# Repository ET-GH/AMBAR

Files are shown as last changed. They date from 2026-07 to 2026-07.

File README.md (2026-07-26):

# AMBAR
The software and hardware of the AMBAR project

Utilized Firmware includes all the logic used for our system.

Measurement & Control includes logic and API used for the measurement and control of the system. Airbrake.c includes references to a tmc5240 driver. Utilized Firmware has the completed driver but if your system used something else then changes must be made in the airbrake logic.

Communication includes logic and api used for communication and data between the flight computer and ground station. radio_bridge includes references to an sx1280 driver. Utilized Firmware has the completed driver but if your system used something else then changes must be made in the bridge logic. usb_comm includes references to the STM32 USB drivers. Utilized Firmware has the completed driver but if your system used something else then changes must be made in the usb logic.

GroundStation includes all the files used for qt application. Qt libraries were used for each of the integration files. The architecture can still be used if you don't want to use QT but the function calls will not work without the installed QT libraries.

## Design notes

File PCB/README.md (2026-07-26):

# AMBAR Flight Computer PCB
What we used for our project. You can buy all the components off of JLCPCB and Digikey

Export the gerber files and the bill of materials. Purchase the electrical componetns from digikey if you plan to solder but it's much easier to simply ask JLCPCB to fabricate and assemble the board.

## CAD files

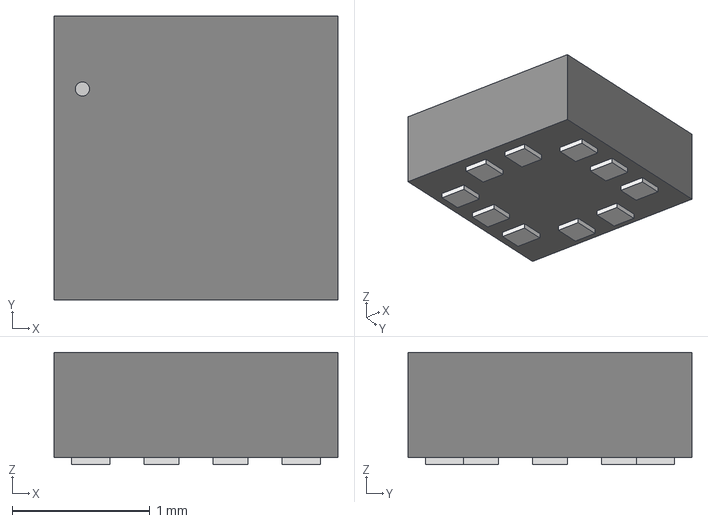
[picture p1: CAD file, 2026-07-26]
PCB/components/ul_BMP388/QFN_BMP388_BOS.step
2.06 x 2.06 x 0.815 mm

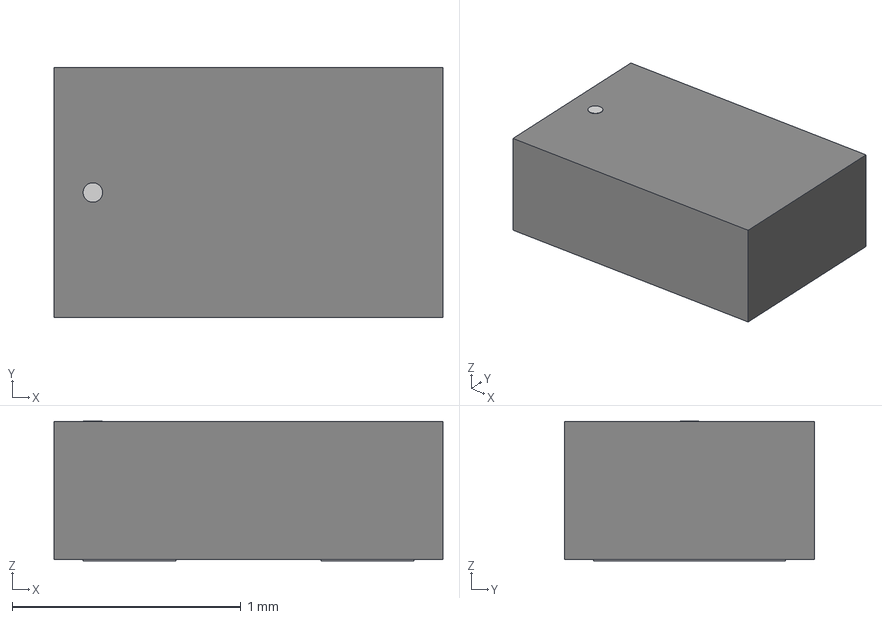
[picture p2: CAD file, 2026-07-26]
PCB/components/ul_ESDA7P60-1U1M/ZDO_1610_STM.step
1.70 x 1.09 x 0.612 mm

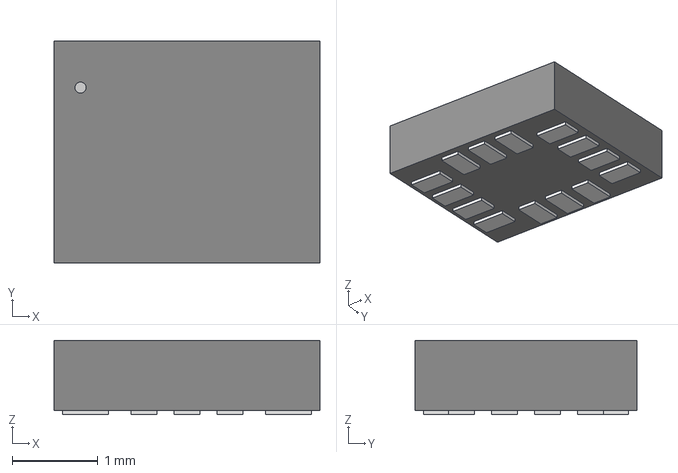
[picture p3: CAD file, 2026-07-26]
PCB/components/ul_LSM6DSV32XTR/LGA-14L_2p5X3p0X0p86_STM.step
3.10 x 2.59 x 0.866 mm

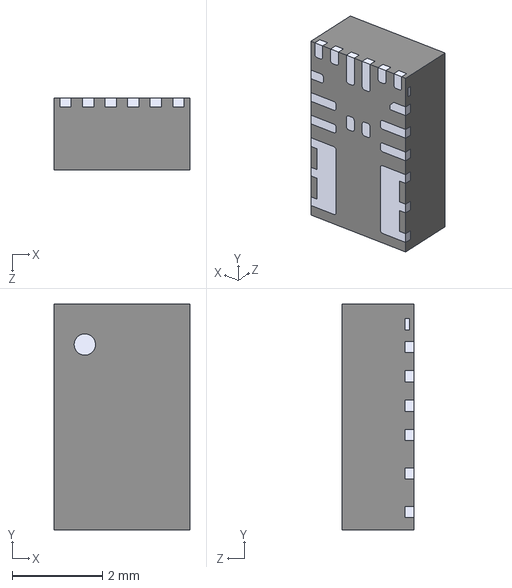
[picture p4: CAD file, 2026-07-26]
PCB/components/ul_MPM3606AGQV-Z/MPM3606AGQV.step
3.00 x 5.00 x 1.60 mm

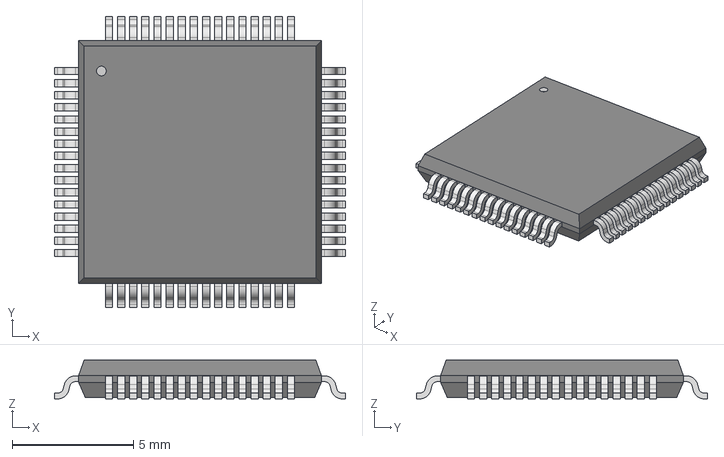
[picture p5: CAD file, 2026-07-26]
PCB/components/ul_STM32H562RGT6/LQFP64-10x10mm_STM.step
12.0 x 12.0 x 1.60 mm

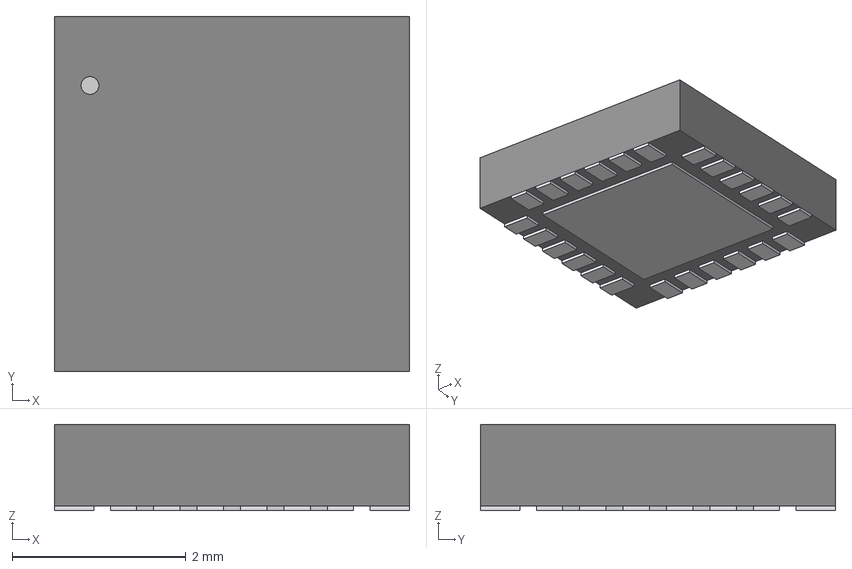
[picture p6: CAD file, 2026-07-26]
PCB/components/ul_SX1280IMLTRT/QFN24_4X4_SEM.step
4.09 x 4.09 x 0.993 mm

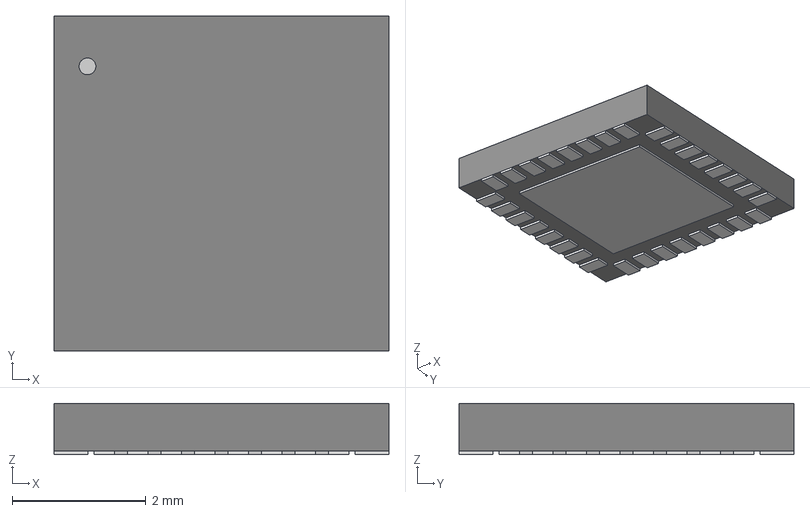
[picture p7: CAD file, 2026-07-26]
PCB/components/ul_TMC5240ATJ-T/21-0140_T32555C_ADI.step
5.00 x 5.00 x 0.765 mm

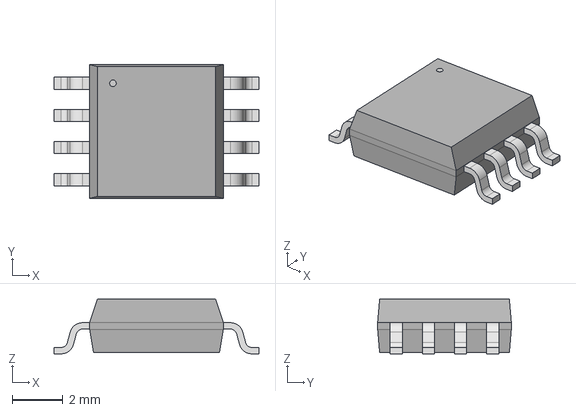
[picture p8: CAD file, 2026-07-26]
PCB/components/ul_W25Q64JVSSIQ/SOIC-8_5P28X5P28_WIN.step
8.10 x 5.28 x 2.16 mm

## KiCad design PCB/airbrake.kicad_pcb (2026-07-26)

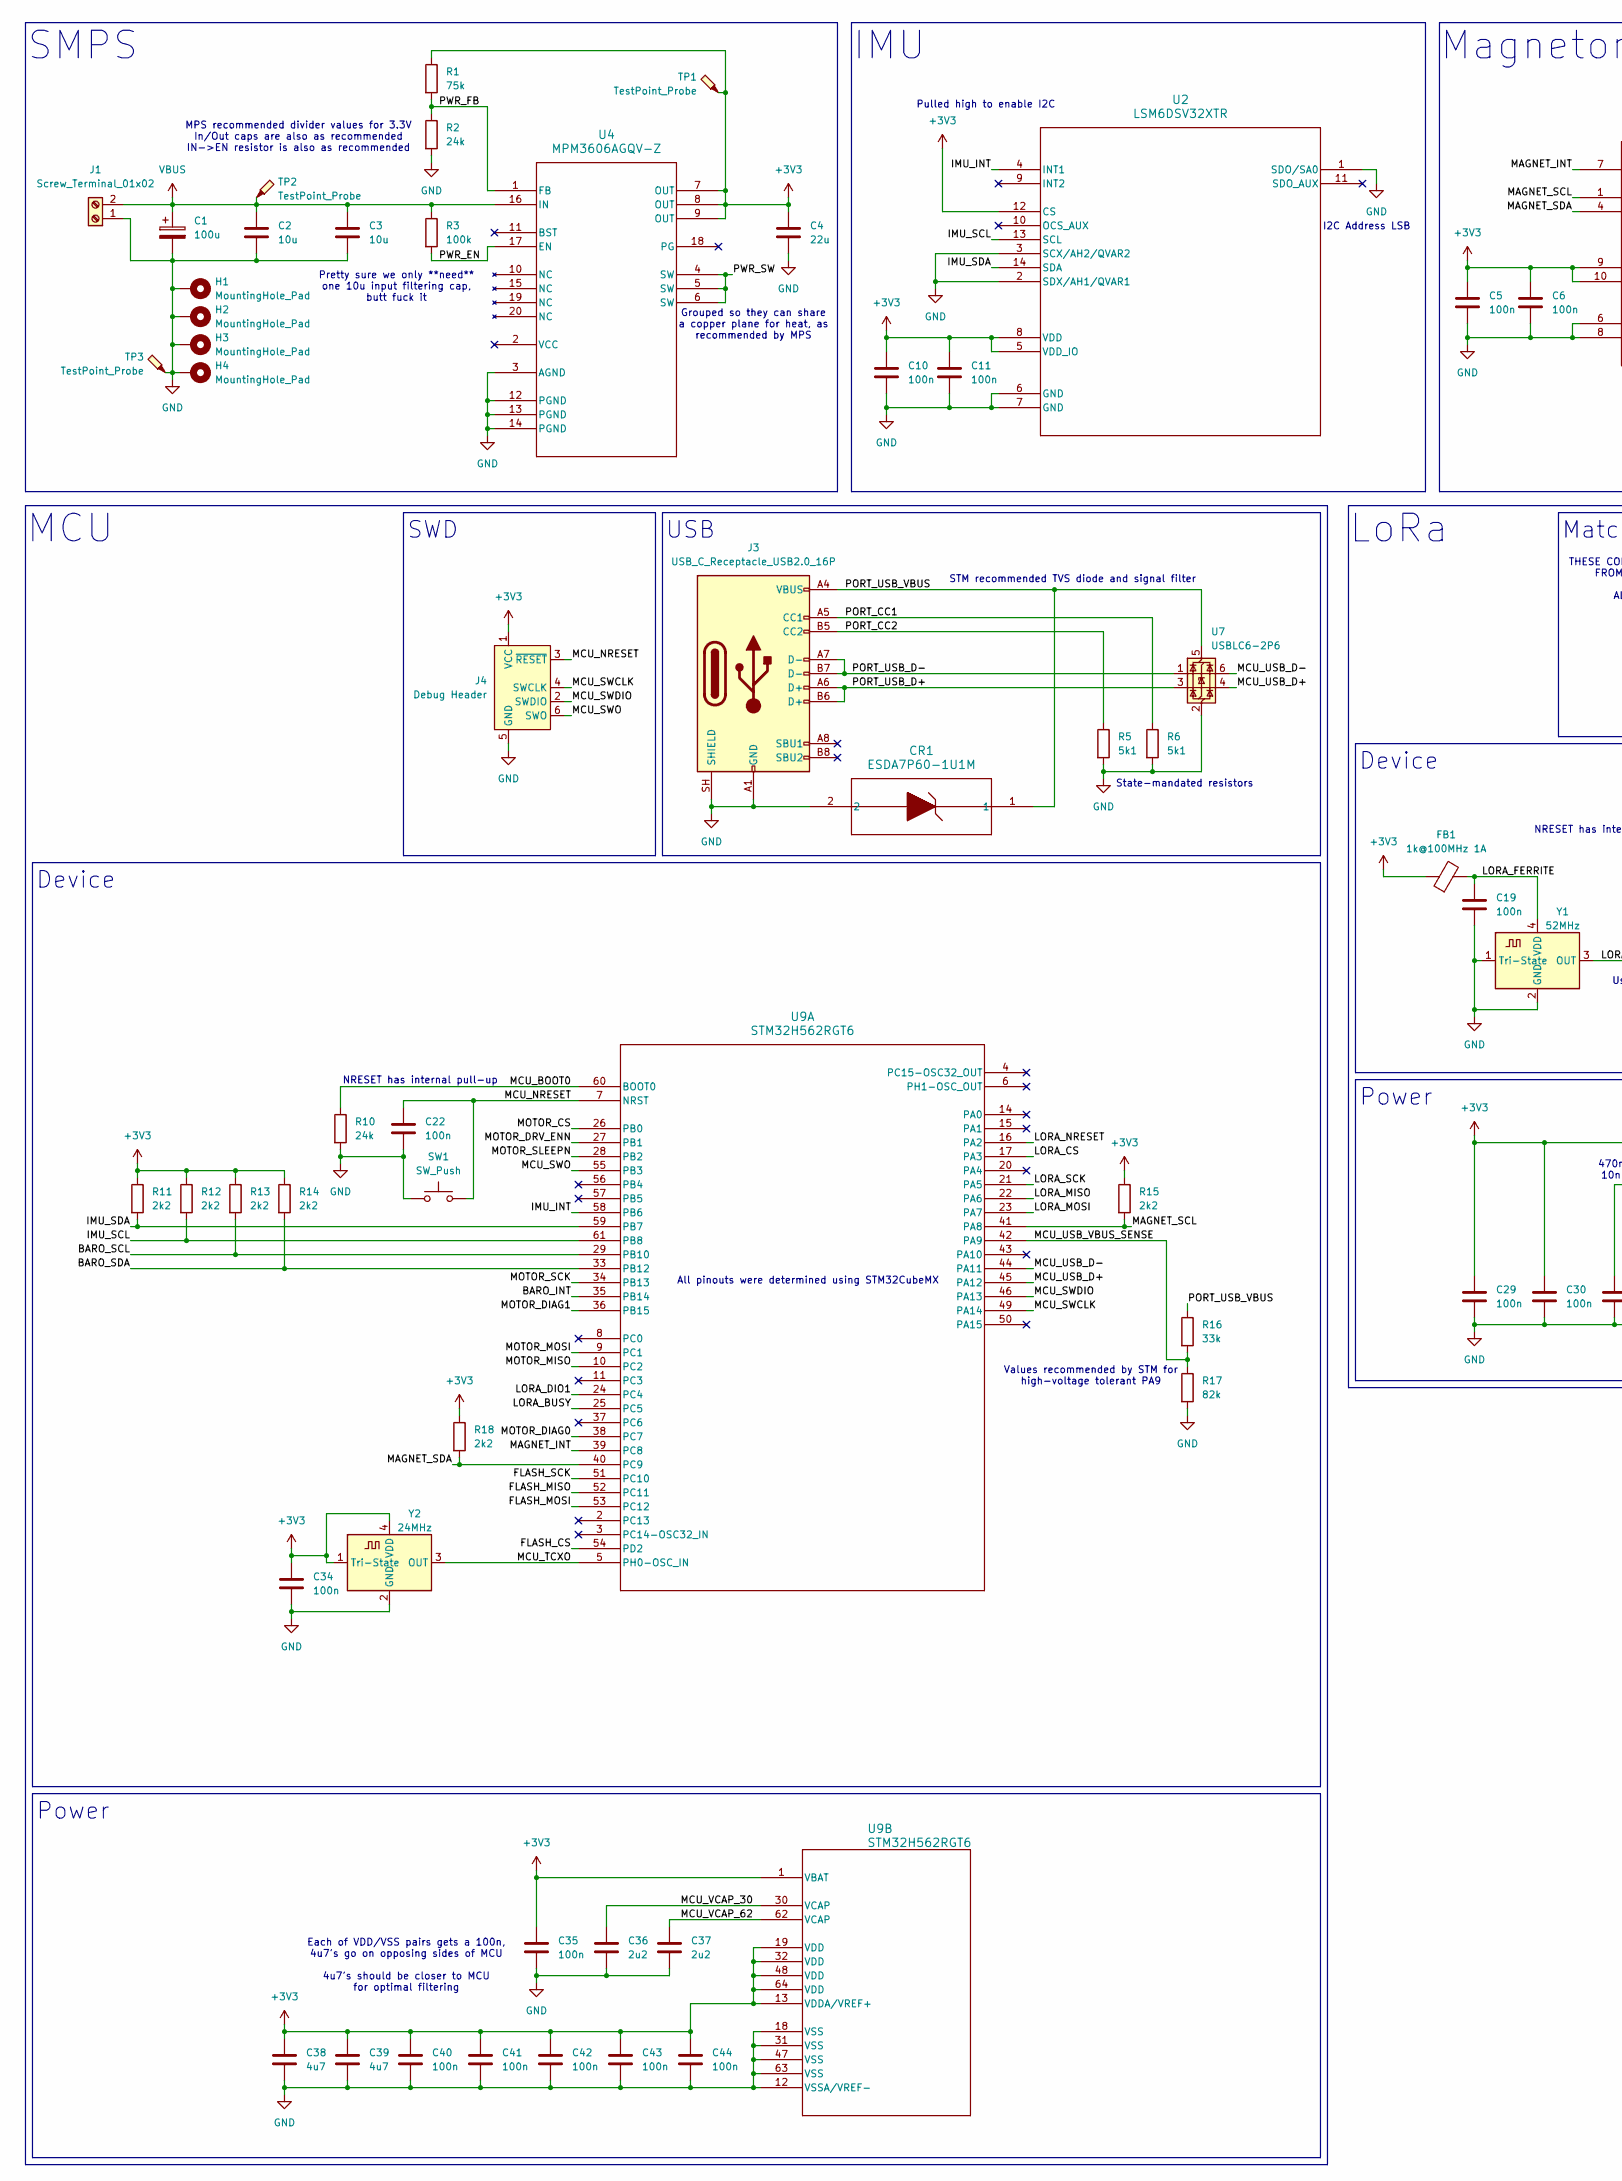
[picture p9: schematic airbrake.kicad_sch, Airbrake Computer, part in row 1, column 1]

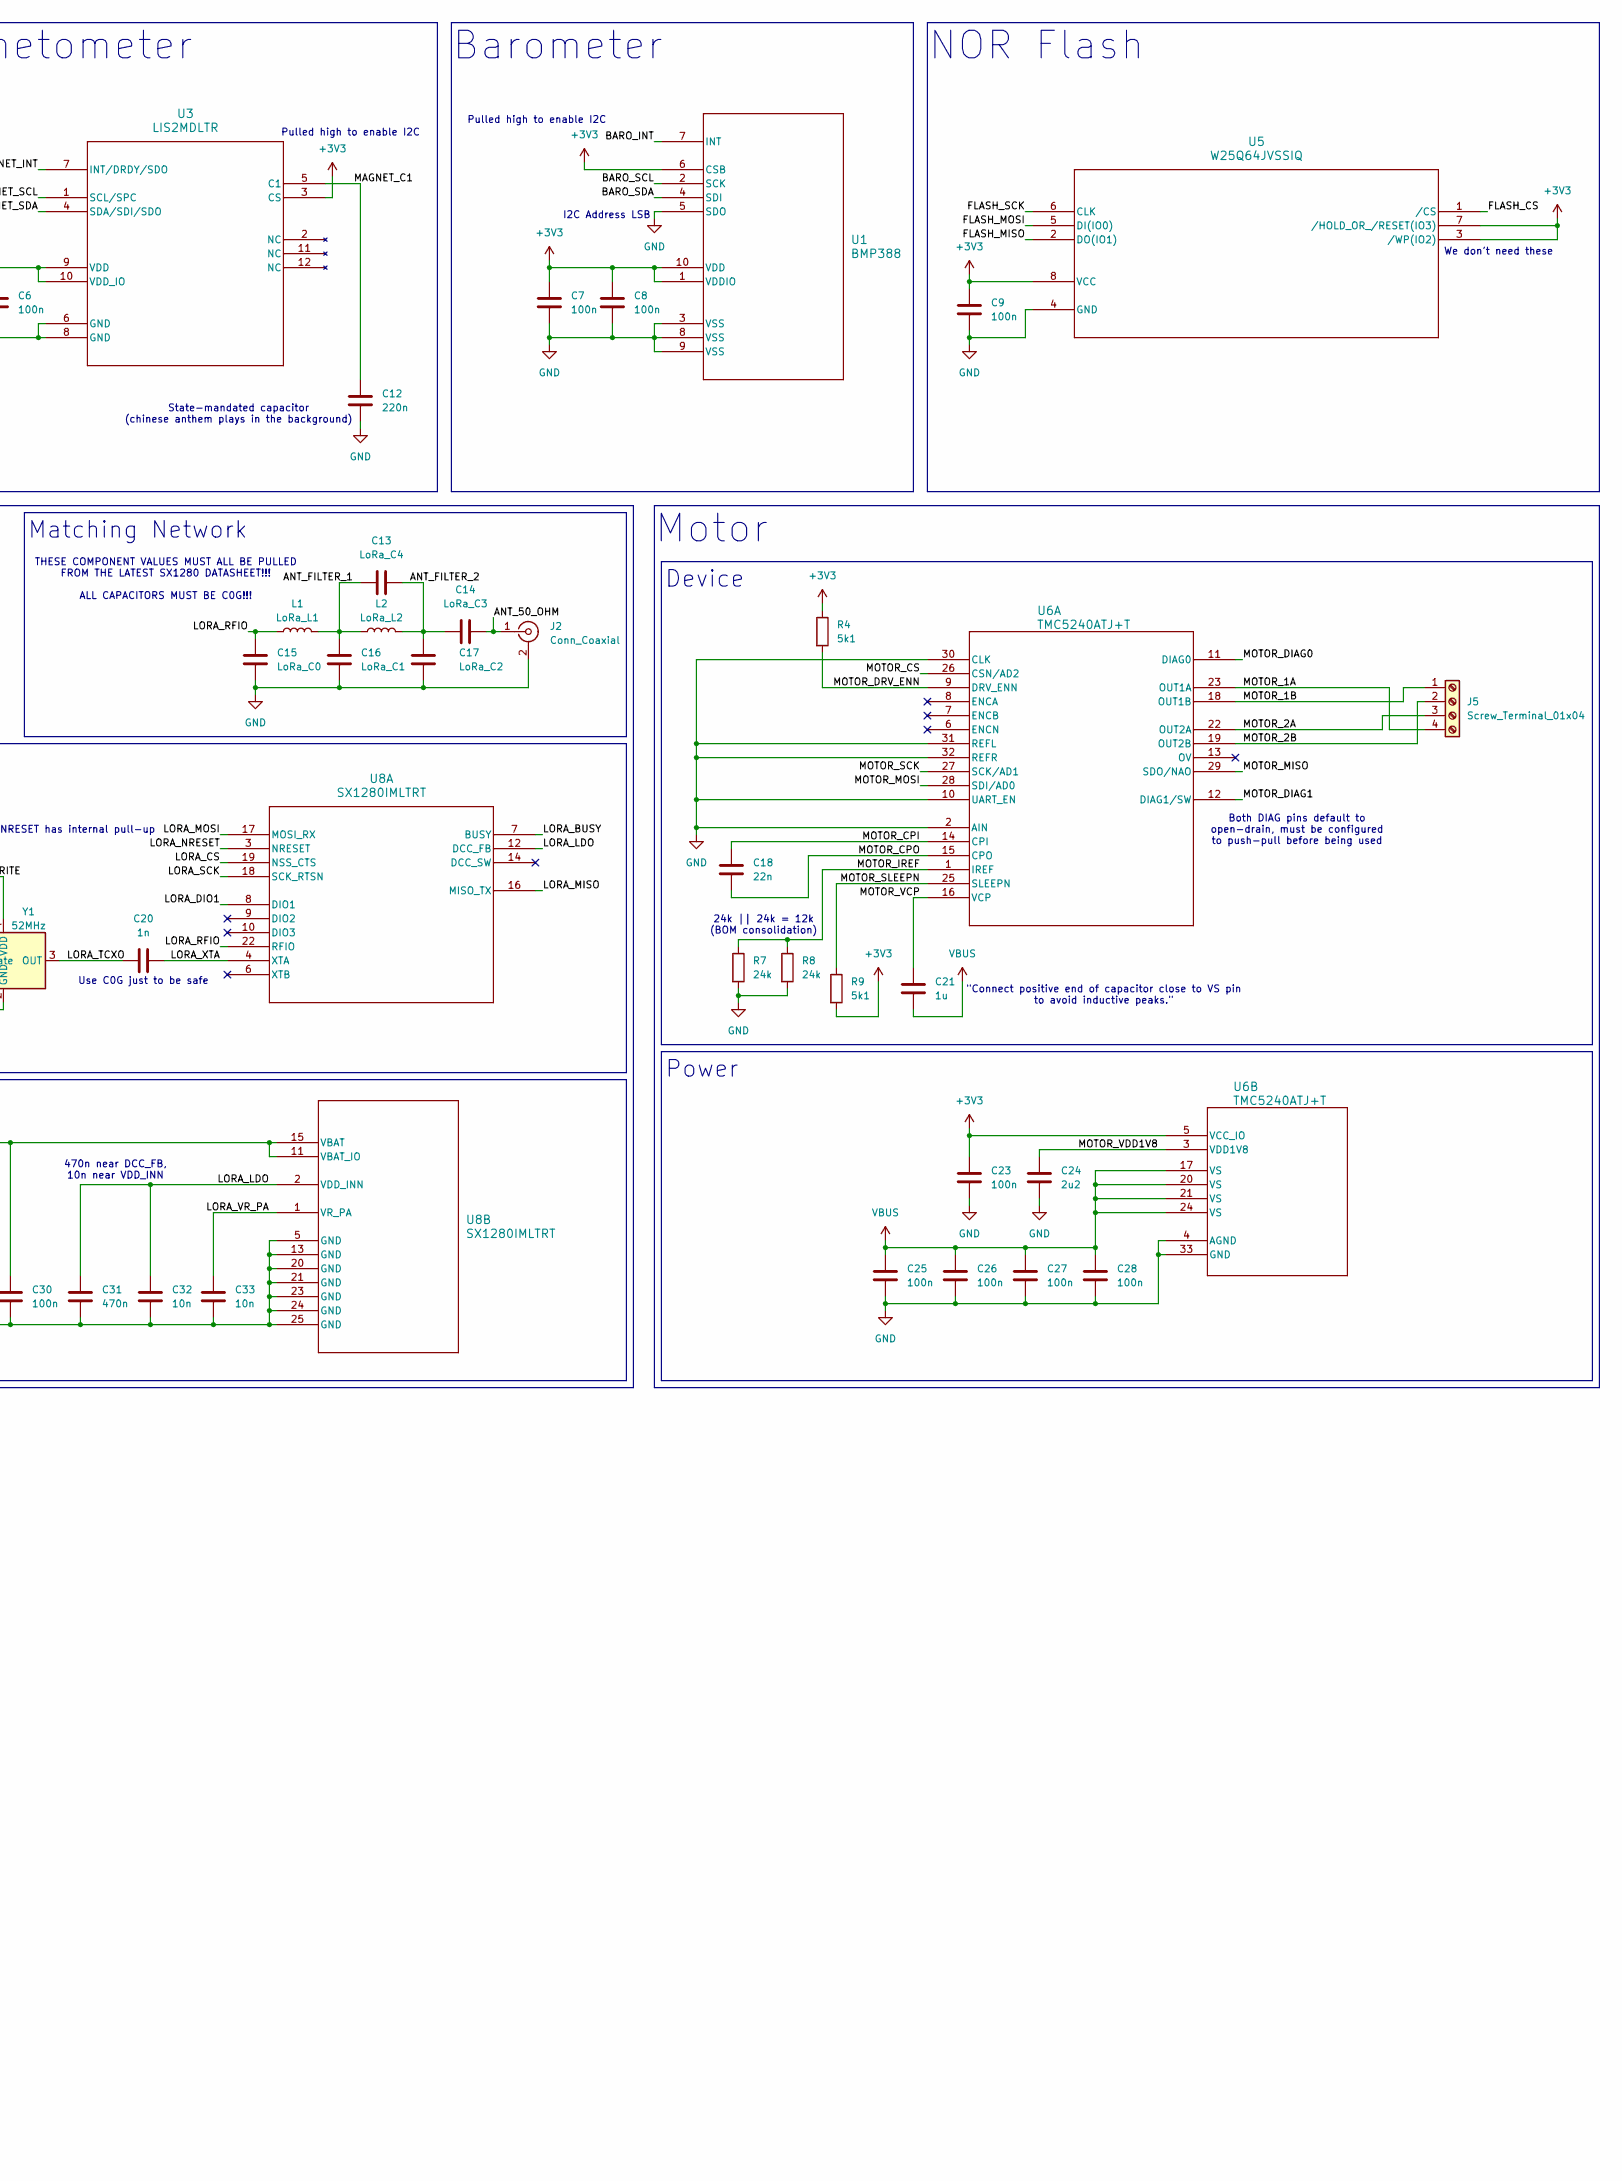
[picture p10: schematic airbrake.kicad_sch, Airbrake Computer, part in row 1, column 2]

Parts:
C1: 100u; CP_Elec_6.3x7.7
C2, C3: 10u; C_0603_1608Metric
C4: 22u; C_0603_1608Metric
C5, C6, C7, C8, C9, C10, C11, C19, C22, C23, C25, C26, C27, C28, C29, C30, C34, C35, C40, C41, C42, C43, C44: 100n; C_0402_1005Metric
C12: 220n; C_0402_1005Metric
C13: LoRa_C4; C_0402_1005Metric
C14: LoRa_C3; C_0402_1005Metric
C15: LoRa_C0; C_0402_1005Metric
C16: LoRa_C1; C_0402_1005Metric
C17: LoRa_C2; C_0402_1005Metric
C18: 22n; C_0402_1005Metric
C20: 1n; C_0402_1005Metric
C21: 1u; C_0402_1005Metric
C24, C36, C37: 2u2; C_0402_1005Metric
C31: 470n; C_0402_1005Metric
C32, C33: 10n; C_0402_1005Metric
C38, C39: 4u7; C_0402_1005Metric
CR1: ESDA7P60-1U1M; ZDO_1610_STM
FB1: 1k@100MHz 1A; L_0603_1608Metric
H1, H2, H3, H4: MountingHole_Pad; MountingHole_2.2mm_M2_Pad_Via
J1: Screw_Terminal_01x02; TerminalBlock_Xinya_XY308-2.54-2P_1x02_P2.54mm_Horizontal
J2: Conn_Coaxial; U.FL_Hirose_U.FL-R-SMT-1_Vertical
J3: USB_C_Receptacle_USB2.0_16P; USB_C_Receptacle_GCT_USB4105-xx-A_16P_TopMnt_Horizontal
J4: Debug Header; Tag-Connect_TC2030-IDC-NL_2x03_P1.27mm_Vertical
J5: Screw_Terminal_01x04; TerminalBlock_Xinya_XY308-2.54-4P_1x04_P2.54mm_Horizontal
L1: LoRa_L1; L_0402_1005Metric
L2: LoRa_L2; L_0402_1005Metric
R1: 75k; R_0402_1005Metric
R2, R7, R8, R10: 24k; R_0402_1005Metric
R3: 100k; R_0402_1005Metric
R4, R5, R6, R9: 5k1; R_0402_1005Metric
R11, R12, R13, R14, R15, R18: 2k2; R_0402_1005Metric
R16: 33k; R_0402_1005Metric
R17: 82k; R_0402_1005Metric
SW1: SW_Push; SW_SPST_B3U-1000P
TP1, TP2, TP3: TestPoint_Probe; TestPoint_Pad_D2.5mm
U1: BMP388; QFN_BMP388_BOS
U2: LSM6DSV32XTR; LGA-14L_2p5X3p0X0p86_STM
U3: LIS2MDLTR; LGA-12_2X2X1_STM
U4: MPM3606AGQV-Z; QFN3p0x5p0x1p6_MPM3606A_MNP
U5: W25Q64JVSSIQ; SOIC-8_5P28X5P28_WIN-L
U6: TMC5240ATJ+T; 21-0140_T3255&plus_5C_ADI-L
U7: USBLC6-2P6; SOT-666
U8: SX1280IMLTRT; QFN24_4X4_SEM-L
U9: STM32H562RGT6; LQFP64-10x10mm_STM
Y1: 52MHz; Crystal_SMD_2016-4Pin_2.0x1.6mm
Y2: 24MHz; Crystal_SMD_2520-4Pin_2.5x2.0mm

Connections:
+3V3: C4.1, C5.1, C6.1, C7.1, C8.1, C9.1, C10.1, C11.1, C23.1, C29.1, C30.1, C34.1, C35.1, C38.1, C39.1, C40.1, C41.1, C42.1, C43.1, C44.1, FB1.1, J4.1 (VCC), R1.1, R4.1, R9.2, R11.1, R12.1, R13.1, R14.1, R15.1, R18.1, TP1.1 (1_1), U1.1 (VDDIO), U1.6 (CSB), U1.10 (VDD), U2.5 (VDD_IO), U2.8 (VDD), U2.12 (CS), U3.3 (CS), U3.9 (VDD), U3.10 (VDD_IO), U4.7 (OUT), U4.8 (OUT), U4.9 (OUT), U5.3 (/WP(IO2)), U5.7 (/HOLD_OR_/RESET(IO3)), U5.8 (VCC), U6.5 (VCC_IO), U8.11 (VBAT_IO), U8.15 (VBAT), U9.1 (VBAT), U9.13 (VDDA/VREF+), U9.19 (VDD), U9.32 (VDD), U9.48 (VDD), U9.64 (VDD), Y2.1 (Tri-State), Y2.4 (VDD)
/ANT_50_OHM: C14.2, J2.1 (In)
/ANT_FILTER_1: C13.1, C16.1, L1.2, L2.1
/ANT_FILTER_2: C13.2, C14.1, C17.1, L2.2
/BARO_INT: U1.7 (INT), U9.35 (PB14)
/BARO_SCL: R13.2, U1.2 (SCK), U9.29 (PB10)
/BARO_SDA: R14.2, U1.4 (SDI), U9.33 (PB12)
/FLASH_CS: U5.1 (/CS), U9.54 (PD2)
/FLASH_MISO: U5.2 (DO(IO1)), U9.52 (PC11)
/FLASH_MOSI: U5.5 (DI(IO0)), U9.53 (PC12)
/FLASH_SCK: U5.6 (CLK), U9.51 (PC10)
/IMU_INT: U2.4 (INT1), U9.58 (PB6)
/IMU_SCL: R12.2, U2.13 (SCL), U9.61 (PB8)
/IMU_SDA: R11.2, U2.14 (SDA), U9.59 (PB7)
/LORA_BUSY: U8.7 (BUSY), U9.25 (PC5)
/LORA_CS: U8.19 (NSS_CTS), U9.17 (PA3)
/LORA_DIO1: U8.8 (DIO1), U9.24 (PC4)
/LORA_FERRITE: C19.1, FB1.2, Y1.4 (VDD)
/LORA_LDO: C31.1, C32.1, U8.2 (VDD_INN), U8.12 (DCC_FB)
/LORA_MISO: U8.16 (MISO_TX), U9.22 (PA6)
/LORA_MOSI: U8.17 (MOSI_RX), U9.23 (PA7)
/LORA_NRESET: U8.3 (NRESET), U9.16 (PA2)
/LORA_RFIO: C15.1, L1.1, U8.22 (RFIO)
/LORA_SCK: U8.18 (SCK_RTSN), U9.21 (PA5)
/LORA_TCXO: C20.1, Y1.3 (OUT)
/LORA_VR_PA: C33.1, U8.1 (VR_PA)
/LORA_XTA: C20.2, U8.4 (XTA)
/MAGNET_C1: C12.1, U3.5 (C1)
/MAGNET_INT: U3.7 (INT/DRDY/SDO), U9.39 (PC8)
/MAGNET_SCL: R15.2, U3.1 (SCL/SPC), U9.41 (PA8)
/MAGNET_SDA: R18.2, U3.4 (SDA/SDI/SDO), U9.40 (PC9)
/MCU_BOOT0: R10.1, U9.60 (BOOT0)
/MCU_NRESET: C22.1, J4.3 (~RESET), SW1.2, U9.7 (NRST)
/MCU_SWCLK: J4.4 (SWCLK), U9.49 (PA14)
/MCU_SWDIO: J4.2 (SWDIO), U9.46 (PA13)
/MCU_SWO: J4.6 (SWO), U9.55 (PB3)
/MCU_TCXO: U9.5 (PH0-OSC_IN), Y2.3 (OUT)
/MCU_USB_D+: U7.4 (I/O2), U9.45 (PA12)
/MCU_USB_D-: U7.6 (I/O1), U9.44 (PA11)
/MCU_USB_VBUS_SENSE: R16.2, R17.1, U9.42 (PA9)
/MCU_VCAP_30: C36.1, U9.30 (VCAP)
/MCU_VCAP_62: C37.1, U9.62 (VCAP)
/MOTOR_1A: J5.4, U6.23 (OUT1A)
/MOTOR_1B: J5.1, U6.18 (OUT1B)
/MOTOR_2A: J5.3, U6.22 (OUT2A)
/MOTOR_2B: J5.2, U6.19 (OUT2B)
/MOTOR_CPI: C18.1, U6.14 (CPI)
/MOTOR_CPO: C18.2, U6.15 (CPO)
/MOTOR_CS: U6.26 (CSN/AD2), U9.26 (PB0)
/MOTOR_DIAG0: U6.11 (DIAG0), U9.38 (PC7)
/MOTOR_DIAG1: U6.12 (DIAG1/SW), U9.36 (PB15)
/MOTOR_DRV_ENN: R4.2, U6.9 (DRV_ENN), U9.27 (PB1)
/MOTOR_IREF: R7.1, R8.1, U6.1 (IREF)
/MOTOR_MISO: U6.29 (SDO/NAO), U9.10 (PC2)
/MOTOR_MOSI: U6.28 (SDI/AD0), U9.9 (PC1)
/MOTOR_SCK: U6.27 (SCK/AD1), U9.34 (PB13)
/MOTOR_SLEEPN: R9.1, U6.25 (SLEEPN), U9.28 (PB2)
/MOTOR_VCP: C21.1, U6.16 (VCP)
/MOTOR_VDD1V8: C24.1, U6.3 (VDD1V8)
/PORT_CC1: J3.A5 (CC1), R6.1
/PORT_CC2: J3.B5 (CC2), R5.1
/PORT_USB_D+: J3.A6 (D+), J3.B6 (D+), U7.3 (I/O2)
/PORT_USB_D-: J3.A7 (D-), J3.B7 (D-), U7.1 (I/O1)
/PORT_USB_VBUS: CR1.1, J3.A4 (VBUS), J3.A9 (VBUS), J3.B4 (VBUS), J3.B9 (VBUS), R16.1, U7.5 (VBUS)
/PWR_EN: R3.2, U4.17 (EN)
/PWR_FB: R1.2, R2.1, U4.1 (FB)
/PWR_SW: U4.4 (SW), U4.5 (SW), U4.6 (SW)
GND: C1.2, C2.2, C3.2, C4.2, C5.2, C6.2, C7.2, C8.2, C9.2, C10.2, C11.2, C12.2, C15.2, C16.2, C17.2, C19.2, C22.2, C23.2, C24.2, C25.2, C26.2, C27.2, C28.2, C29.2, C30.2, C31.2, C32.2, C33.2, C34.2, C35.2, C36.2, C37.2, C38.2, C39.2, C40.2, C41.2, C42.2, C43.2, C44.2, CR1.2, H1.1 (1_1), H2.1 (1_1), H3.1 (1_1), H4.1 (1_1), J1.1, J2.2 (Ext), J3.A1 (GND), J3.A12 (GND), J3.B1 (GND), J3.B12 (GND), J3.SH (SHIELD), J4.5 (GND), R2.2, R5.2, R6.2, R7.2, R8.2, R10.2, R17.2, SW1.1, TP3.1 (1_1), U1.3 (VSS), U1.5 (SDO), U1.8 (VSS), U1.9 (VSS), U2.1 (SDO/SA0), U2.2 (SDX/AH1/QVAR1), U2.3 (SCX/AH2/QVAR2), U2.6 (GND), U2.7 (GND), U3.6 (GND), U3.8 (GND), U4.3 (AGND), U4.12 (PGND), U4.13 (PGND), U4.14 (PGND), U5.4 (GND), U6.2 (AIN), U6.4 (AGND), U6.10 (UART_EN), U6.30 (CLK), U6.31 (REFL), U6.32 (REFR), U6.33 (GND), U7.2 (GND), U8.5 (GND), U8.13 (GND), U8.20 (GND), U8.21 (GND), U8.23 (GND), U8.24 (GND), U8.25 (GND), U9.12 (VSSA/VREF-), U9.18 (VSS), U9.31 (VSS), U9.47 (VSS), U9.63 (VSS), Y1.1 (Tri-State), Y1.2 (GND), Y2.2 (GND)
VBUS: C1.1, C2.1, C3.1, C21.2, C25.1, C26.1, C27.1, C28.1, J1.2, R3.1, TP2.1 (1_1), U4.16 (IN), U6.17 (VS), U6.20 (VS), U6.21 (VS), U6.24 (VS)

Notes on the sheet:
MCU
NRESET has internal pull-up
Pulled high to enable I2C
Each of VDD/VSS pairs gets a 100n, 4u7's go on opposing sides of MCU 4u7's should be closer to MCU for optimal filtering
Values recommended by STM for high-voltage tolerant PA9
State-mandated resistors
All pinouts were determined using STM32CubeMX
Motor
SMPS
Power
Device
I2C Address LSB
Use C0G just to be safe
Barometer
Matching Network
470n near DCC_FB, 10n near VDD_INN
NOR Flash
24k || 24k = 12k (BOM consolidation)
Both DIAG pins default to open-drain, must be configured to push-pull before being used
SWD
LoRa
MPS recommended divider values for 3.3V In/Out caps are also as recommended IN->EN resistor is also as recommended
IMU
Grouped so they can share a copper plane for heat, as recommended by MPS
Magnetometer
"Connect positive end of capacitor close to VS pin to avoid inductive peaks."
USB
State-mandated capacitor (chinese anthem plays in the background)
THESE COMPONENT VALUES MUST ALL BE PULLED FROM THE LATEST SX1280 DATASHEET!!! ALL CAPACITORS MUST BE C0G!!!
We don't need these
Pretty sure we only **need** one 10u input filtering cap, butt fuck it
STM recommended TVS diode and signal filter

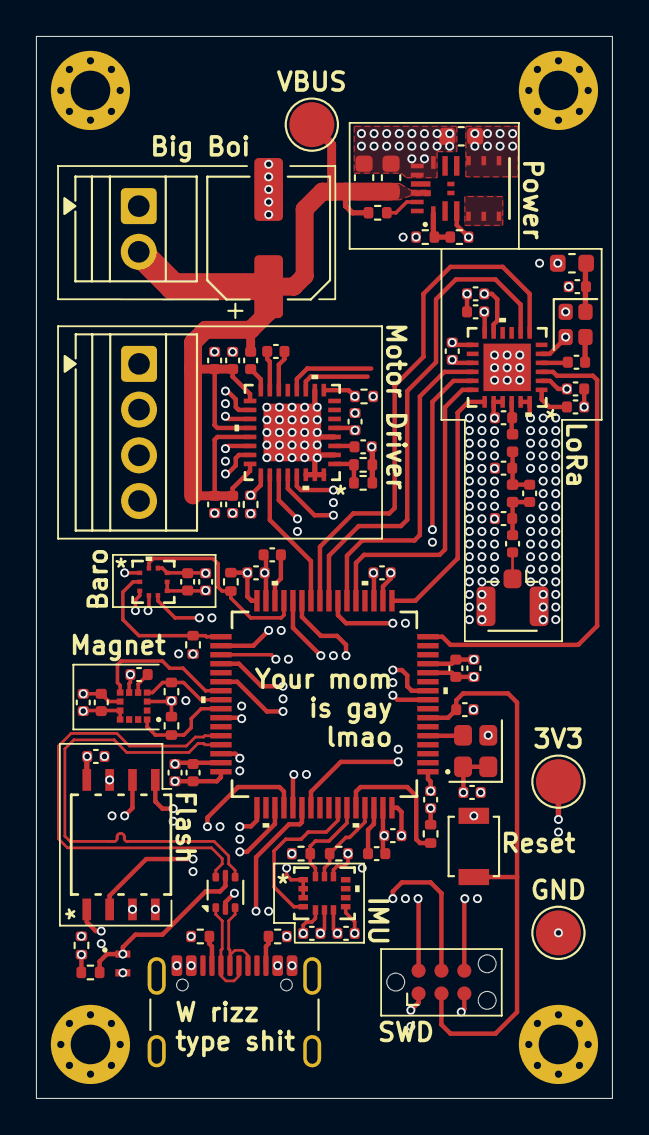
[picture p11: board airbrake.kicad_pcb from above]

Board: 6 copper layers, 32.0 x 59.0 mm, 90 parts (0 on the bottom side), 69 nets.

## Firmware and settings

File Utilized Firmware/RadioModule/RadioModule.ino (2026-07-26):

#include <Arduino.h>
#include <RadioLib.h>
#include <SPI.h>
#include <stdlib.h>
#include <string.h>
#include "rocket_protocol.h"

#define LORA_SCK 5
#define LORA_MISO 3
#define LORA_MOSI 6
#define LORA_CS 7
#define LORA_RST 8
#define LORA_DIO1 9
#define LORA_BUSY 36
#define LORA_TXEN 10
#define LORA_RXEN 21

static constexpr uint32_t UART_BAUD_RATE = 115200;
static constexpr float RADIO_FREQUENCY_MHZ = 2445.0;
static constexpr float RADIO_BANDWIDTH_KHZ = 203.125;
static constexpr uint8_t RADIO_SPREADING_FACTOR = 8;
static constexpr uint8_t RADIO_CODING_RATE_DENOMINATOR = 5;
static constexpr int8_t RADIO_TX_POWER_DBM = 3;
static constexpr uint16_t RADIO_PREAMBLE_SYMBOLS = 12;

/* Explicit wire sizes. Do not use sizeof(struct), because compiler padding may differ. */
static constexpr size_t TELEMETRY_PAYLOAD_SIZE = 26u;
static constexpr size_t EVENT_PAYLOAD_SIZE = 10u;
static constexpr size_t ACK_PAYLOAD_SIZE = 11u;

/*
 * UART records are newline-terminated CSV and contain no spaces.
 *
 * S,status_code,detail
 * T,seq,time_ms,rssi,snr,flags,state,status,alt_dm,vel_cms,acc_cms2,
 *   predicted_dm,target_dm,roll_ddeg,pitch_ddeg,yaw_ddeg,deployment_pct,
 *   sensor_health,failed_reads,message
 * E,seq,time_ms,rssi,snr,changed_flags,current_flags,previous_state,
 *   current_state,status,message,detail
 * A,seq,time_ms,rssi,snr,command_seq,command,result,detail_type,part_index,
 *   part_count,detail
 * H,seq,time_ms,rssi,snr
 * P,source,command_seq,time_ms,link_rssi,link_snr,uptime_ms,tx_packets,
 *   rx_packets,tx_errors,rx_errors,module_last_rssi,module_last_snr,rtt_ms
 *
 * Commands received from the computer use:
 * C,command_code[,argument_0[,argument_1]]
 * Numeric fields may be decimal or 0x-prefixed hexadecimal.
 */
enum GroundStationStatusCode : uint8_t {
  GS_STATUS_BOOT = 0,
  GS_STATUS_RADIO_READY = 1,
  GS_STATUS_RADIO_INIT_FAILED = 2,
  GS_STATUS_RECEIVE_START_FAILED = 3,
  GS_STATUS_RECEIVE_FAILED = 4,
  GS_STATUS_BAD_PACKET_HEADER = 5,
  GS_STATUS_BAD_PACKET_LENGTH = 6,
  GS_STATUS_UNKNOWN_PACKET_TYPE = 7,
  GS_STATUS_PACKET_TOO_LARGE = 8,
  GS_STATUS_SERIAL_OVERFLOW = 9,
  GS_STATUS_SERIAL_BAD_FORMAT = 10,
  GS_STATUS_SERIAL_BAD_COMMAND = 11,
  GS_STATUS_SERIAL_BAD_VALUE = 12,
  GS_STATUS_TRANSMIT_FAILED = 13
};

SX1280 radio = new Module(LORA_CS, LORA_DIO1, LORA_RST, LORA_BUSY);
volatile bool rxFlag = false;
static uint16_t commandSequence = 0;
struct PendingPingResponse {
  uint16_t commandSequence;
  uint32_t sentMs;
  uint32_t rttMs;
  uint32_t uptimeMs;
  uint8_t txPackets;
  uint8_t rxPackets;
  uint8_t txErrors;
  uint8_t rxErrors;
  int16_t lastRssiX10;
  int16_t lastSnrX100;
  uint8_t receivedMask;
  bool active;
  bool rttValid;
};

static PendingPingResponse pendingPing = {};
static uint32_t groundTxPackets = 0;
static uint32_t groundRxPackets = 0;
static uint16_t groundTxErrors = 0;
static uint16_t groundRxErrors = 0;
static uint8_t groundTxSincePing = 0;
static uint8_t groundRxSincePing = 0;
static uint8_t groundTxErrorsSincePing = 0;
static uint8_t groundRxErrorsSincePing = 0;
static float groundLastRssi = 0.0f;
static float groundLastSnr = 0.0f;

void onRadioDio1() {
  rxFlag = true;
}

static void printGroundStatus(uint8_t statusCode, int32_t detail = 0) {
  Serial.print("S,");
  Serial.print(statusCode);
  Serial.print(',');
  Serial.println(detail);
}

static bool startReceiveMode() {
  const int state = radio.startReceive();
  if (state != RADIOLIB_ERR_NONE) {
    printGroundStatus(GS_STATUS_RECEIVE_START_FAILED, state);
    return false;
  }
  return true;
}

static void printTelemetry(const uint8_t *packet,
                           const RocketPacketHeader &header,
                           float rssi,
                           float snr) {
  size_t i = ROCKET_PROTOCOL_HEADER_SIZE;
  const uint16_t flags = RocketProtocol_ReadU16(packet + i); i += 2;
  const uint8_t state = packet[i++];
  const uint8_t status = packet[i++];
  const int16_t altitudeDm = RocketProtocol_ReadI16(packet + i); i += 2;
  const int16_t velocityCms = RocketProtocol_ReadI16(packet + i); i += 2;
  const int16_t accelerationCms2 = RocketProtocol_ReadI16(packet + i); i += 2;
  const uint16_t predictedApogeeDm = RocketProtocol_ReadU16(packet + i); i += 2;
  const uint16_t targetApogeeDm = RocketProtocol_ReadU16(packet + i); i += 2;
  const int16_t rollDdeg = RocketProtocol_ReadI16(packet + i); i += 2;
  const int16_t pitchDdeg = RocketProtocol_ReadI16(packet + i); i += 2;
  const int16_t yawDdeg = RocketProtocol_ReadI16(packet + i); i += 2;
  const uint8_t deploymentPercent = packet[i++];
  const uint8_t sensorHealth = packet[i++];
  const uint16_t failedReads = RocketProtocol_ReadU16(packet + i); i += 2;
  const uint8_t message = packet[i++];

  Serial.print("T,");
  Serial.print(header.sequence); Serial.print(',');
  Serial.print(header.time_ms); Serial.print(',');
  Serial.print(rssi, 1); Serial.print(',');
  Serial.print(snr, 2); Serial.print(',');
  Serial.print(flags); Serial.print(',');
  Serial.print(state); Serial.print(',');
  Serial.print(status); Serial.print(',');
  Serial.print(altitudeDm); Serial.print(',');
  Serial.print(velocityCms); Serial.print(',');
  Serial.print(accelerationCms2); Serial.print(',');
  Serial.print(predictedApogeeDm); Serial.print(',');
  Serial.print(targetApogeeDm); Serial.print(',');
  Serial.print(rollDdeg); Serial.print(',');
  Serial.print(pitchDdeg); Serial.print(',');
  Serial.print(yawDdeg); Serial.print(',');
  Serial.print(deploymentPercent); Serial.print(',');
  Serial.print(sensorHealth); Serial.print(',');
  Serial.print(failedReads); Serial.print(',');
  Serial.println(message);
}

static void printEvent(const uint8_t *packet,
                       const RocketPacketHeader &header,
                       float rssi,
                       float snr) {
  size_t i = ROCKET_PROTOCOL_HEADER_SIZE;
  const uint16_t changedFlags = RocketProtocol_ReadU16(packet + i); i += 2;
  const uint16_t currentFlags = RocketProtocol_ReadU16(packet + i); i += 2;
  const uint8_t previousState = packet[i++];
  const uint8_t currentState = packet[i++];
  const uint8_t status = packet[i++];
  const uint8_t message = packet[i++];
  const uint16_t detail = RocketProtocol_ReadU16(packet + i);

  Serial.print("E,");
  Serial.print(header.sequence); Serial.print(',');
  Serial.print(header.time_ms); Serial.print(',');
  Serial.print(rssi, 1); Serial.print(',');
  Serial.print(snr, 2); Serial.print(',');
  Serial.print(changedFlags); Serial.print(',');
  Serial.print(currentFlags); Serial.print(',');
  Serial.print(previousState); Serial.print(',');
  Serial.print(currentState); Serial.print(',');
  Serial.print(status); Serial.print(',');
  Serial.print(message); Serial.print(',');
  Serial.println(detail);
}

static void printAck(const uint8_t *packet,
                     const RocketPacketHeader &header,
                     float rssi,
                     float snr) {
  size_t i = ROCKET_PROTOCOL_HEADER_SIZE;
  const uint16_t acknowledgedSequence = RocketProtocol_ReadU16(packet + i); i += 2;
  const uint8_t command = packet[i++];
  const uint8_t result = packet[i++];
  const uint8_t detailType = packet[i++];
  const uint8_t partIndex = packet[i++];
  const uint8_t partCount = packet[i++];
  const uint32_t detail = RocketProtocol_ReadU32(packet + i);

  Serial.print("A,");
  Serial.print(header.sequence); Serial.print(',');
  Serial.print(header.time_ms); Serial.print(',');
  Serial.print(rssi, 1); Serial.print(',');
  Serial.print(snr, 2); Serial.print(',');
  Serial.print(acknowledgedSequence); Serial.print(',');
  Serial.print(command); Serial.print(',');
  Serial.print(result); Serial.print(',');
  Serial.print(detailType); Serial.print(',');
  Serial.print(partIndex); Serial.print(',');
  Serial.print(partCount); Serial.print(',');
  Serial.println(detail);

  /* A ping is returned as several ACKs. The first ACK establishes RTT; later
   * ACKs only add statistics and therefore do not change the RTT measurement. */
  if (!pendingPing.active ||
      command != ROCKET_CMD_PING ||
      acknowledgedSequence != pendingPing.commandSequence) {
    return;
  }

  if (result != ROCKET_ACK_OK) {
    pendingPing.active = false;
    return;
  }

  if (partIndex == 0u && !pendingPing.rttValid) {
    pendingPing.rttMs = millis() - pendingPing.sentMs;
    pendingPing.rttValid = true;
  }

  switch (detailType) {
    case ROCKET_ACK_DETAIL_PING_UPTIME:
      pendingPing.uptimeMs = detail;
      pendingPing.receivedMask |= 0x01u;
      break;

    case ROCKET_ACK_DETAIL_PING_COUNTERS:
      pendingPing.txPackets = static_cast<uint8_t>(detail >> 24);
      pendingPing.rxPackets = static_cast<uint8_t>(detail >> 16);
      pendingPing.txErrors = static_cast<uint8_t>(detail >> 8);
      pendingPing.rxErrors = static_cast<uint8_t>(detail);
      pendingPing.receivedMask |= 0x02u;
      break;

    case ROCKET_ACK_DETAIL_PING_SIGNAL:
      pendingPing.lastRssiX10 = static_cast<int16_t>(detail >> 16);
      pendingPing.lastSnrX100 = static_cast<int16_t>(detail & 0xFFFFu);
      pendingPing.receivedMask |= 0x04u;
      break;
  }

  if ((pendingPing.receivedMask & 0x07u) == 0x07u) {
    Serial.print("P,F,");
    Serial.print(acknowledgedSequence); Serial.print(',');
    Serial.print(header.time_ms); Serial.print(',');
    Serial.print(rssi, 1); Serial.print(',');
    Serial.print(snr, 2); Serial.print(',');
    Serial.print(pendingPing.uptimeMs); Serial.print(',');
    Serial.print(pendingPing.txPackets); Serial.print(',');
    Serial.print(pendingPing.rxPackets); Serial.print(',');
    Serial.print(pendingPing.txErrors); Serial.print(',');
    Serial.print(pendingPing.rxErrors); Serial.print(',');
    Serial.print(pendingPing.lastRssiX10 / 10.0f, 1); Serial.print(',');
    Serial.print(pendingPing.lastSnrX100 / 100.0f, 2); Serial.print(',');
    if (pendingPing.rttValid) Serial.println(pendingPing.rttMs);
    else Serial.println(-1);
    pendingPing.active = false;
  }
}

static void printHeartbeat(const RocketPacketHeader &header, float rssi, float snr) {
  Serial.print("H,");
  Serial.print(header.sequence); Serial.print(',');
  Serial.print(header.time_ms); Serial.print(',');
  Serial.print(rssi, 1); Serial.print(',');
  Serial.println(snr, 2);
}

static void parsePacket(const uint8_t *packet, size_t length, float rssi, float snr) {
  RocketPacketHeader header;
  if (!RocketProtocol_DecodeHeader(packet, length, &header)) {
    printGroundStatus(GS_STATUS_BAD_PACKET_HEADER, static_cast<int32_t>(length));
    return;
  }

  size_t requiredLength = ROCKET_PROTOCOL_HEADER_SIZE;
  switch (header.type) {
    case ROCKET_PKT_TELEMETRY:
      requiredLength += TELEMETRY_PAYLOAD_SIZE;
      break;
    case ROCKET_PKT_EVENT:
      requiredLength += EVENT_PAYLOAD_SIZE;
      break;
    case ROCKET_PKT_ACK:
      requiredLength += ACK_PAYLOAD_SIZE;
      break;
    case ROCKET_PKT_HEARTBEAT:
      break;
    default:
      printGroundStatus(GS_STATUS_UNKNOWN_PACKET_TYPE, header.type);
      return;
  }

  if (length < requiredLength) {
    const int32_t detail = (static_cast<int32_t>(requiredLength) << 16)
                         | static_cast<int32_t>(length & 0xFFFFu);
    printGroundStatus(GS_STATUS_BAD_PACKET_LENGTH, detail);
    return;
  }

  switch (header.type) {
    case ROCKET_PKT_TELEMETRY:
      printTelemetry(packet, header, rssi, snr);
      break;
    case ROCKET_PKT_EVENT:
      printEvent(packet, header, rssi, snr);
      break;
    case ROCKET_PKT_ACK:
      printAck(packet, header, rssi, snr);
      break;
    case ROCKET_PKT_HEARTBEAT:
      printHeartbeat(header, rssi, snr);
      break;
  }
}

/* Parses one complete CSV command, validates its arguments, builds the binary
 * protocol packet, and transmits it to the flight computer. */
static bool sendSerialCommand(char *line) {
  char *fields[4] = {nullptr, nullptr, nullptr, nullptr};
  char *save = nullptr;
  size_t fieldCount = 0;

  for (char *token = strtok_r(line, ",", &save); token != nullptr;
       token = strtok_r(nullptr, ",", &save)) {
    if (fieldCount >= 4) {
      printGroundStatus(GS_STATUS_SERIAL_BAD_FORMAT, 4);
      return false;
    }
    fields[fieldCount++] = token;
  }

  if (fieldCount < 2 || strcmp(fields[0], "C") != 0) {
    printGroundStatus(GS_STATUS_SERIAL_BAD_FORMAT, static_cast<int32_t>(fieldCount));
    return false;
  }

  auto parseNumber = [](const char *text, long &value) -> bool {
    if (text == nullptr || *text == '\0') return false;
    char *end = nullptr;
    value = strtol(text, &end, 0);
    return end != text && *end == '\0';
  };

  long commandValue = 0;
  long argument0 = 0;
  long argument1 = 0;
  if (!parseNumber(fields[1], commandValue) || commandValue < 0 || commandValue > 255) {
    printGroundStatus(GS_STATUS_SERIAL_BAD_COMMAND, commandValue);
    return false;
  }
  if (fieldCount >= 3 && !parseNumber(fields[2], argument0)) {
    printGroundStatus(GS_STATUS_SERIAL_BAD_VALUE, 0);
    return false;
  }
  if (fieldCount >= 4 && !parseNumber(fields[3], argument1)) {
    printGroundStatus(GS_STATUS_SERIAL_BAD_VALUE, 1);
    return false;
  }

  const uint8_t command = static_cast<uint8_t>(commandValue);
  uint8_t payload[8] = {0};
  uint8_t payloadLength = 0;

  switch (command) {
    case ROCKET_CMD_NOP:
    case ROCKET_CMD_PING:
    case ROCKET_CMD_REQUEST_SNAPSHOT:
    case ROCKET_CMD_RETURN_STANDARD:
    case ROCKET_CMD_CLEAR_FAULTS:
    case ROCKET_CMD_CLEAR_MEMORY:
      if (fieldCount != 2) goto badLength;
      break;

    case ROCKET_CMD_SET_TARGET_APOGEE:
      if (fieldCount != 3) goto badLength;
      if (argument0 < 0 || argument0 > 65535) goto badValue;
      RocketProtocol_WriteU16(payload, static_cast<uint16_t>(argument0));
      payloadLength = 2;
      break;

    case ROCKET_CMD_SET_CONTROLLER:
      if (fieldCount != 3) goto badLength;
      if (argument0 < 0 || argument0 > 1) goto badValue;
      payload[0] = static_cast<uint8_t>(argument0);
      payloadLength = 1;
      break;

    case ROCKET_CMD_SET_MODE:
      if (fieldCount != 3 && fieldCount != 4) goto badLength;
      if (argument0 < ROCKET_MODE_STANDBY || argument0 > ROCKET_MODE_TEST ||
          argument1 < 0 || argument1 > 65535) goto badValue;
      payload[0] = static_cast<uint8_t>(argument0);
      RocketProtocol_WriteU16(payload + 1, static_cast<uint16_t>(argument1));
      payloadLength = 3;
      break;

    case ROCKET_CMD_MANUAL_AIRBRAKE:
      if (fieldCount != 3) goto badLength;
      if (argument0 < 0 || argument0 > 100) goto badValue;
      payload[0] = static_cast<uint8_t>(argument0);
      payloadLength = 1;
      break;

    case ROCKET_CMD_SET_SUBSYSTEM:
      if (fieldCount != 4) goto badLength;
      if (argument0 < ROCKET_SUBSYSTEM_RADIO ||
          argument0 > ROCKET_SUBSYSTEM_FLIGHT_COMPUTER ||
          argument1 < 0 || argument1 > 1) goto badValue;
      payload[0] = static_cast<uint8_t>(argument0);
      payload[1] = static_cast<uint8_t>(argument1);
      payloadLength = 2;
      break;

    case ROCKET_CMD_MOTOR_STEPS:
      if (fieldCount != 3) goto badLength;
      if (argument0 < -32768 || argument0 > 32767) goto badValue;
      RocketProtocol_WriteI16(payload, static_cast<int16_t>(argument0));
      payloadLength = 2;
      break;

    case ROCKET_CMD_REQUEST_DIAGNOSTICS:
      if (fieldCount != 2 && fieldCount != 3) goto badLength;
      if (argument0 < ROCKET_DIAG_ALL || argument0 > ROCKET_DIAG_STORAGE) goto badValue;
      payload[0] = static_cast<uint8_t>(argument0);
      payloadLength = 1;
      break;

    default:
      printGroundStatus(GS_STATUS_SERIAL_BAD_COMMAND, command);
      return false;
  }

  {
    const uint16_t sequence = ++commandSequence;
    const uint32_t nowMs = millis();
    uint8_t packet[ROCKET_PROTOCOL_HEADER_SIZE + 2u + sizeof(payload)] = {0};
    RocketProtocol_EncodeHeader(packet, sizeof(packet), ROCKET_PKT_COMMAND, sequence, nowMs);
    packet[ROCKET_PROTOCOL_HEADER_SIZE] = command;
    packet[ROCKET_PROTOCOL_HEADER_SIZE + 1u] = payloadLength;
    memcpy(packet + ROCKET_PROTOCOL_HEADER_SIZE + 2u, payload, payloadLength);

    /* Report this module immediately. The one-byte counters cover activity
     * since the previous ping and saturate at 255 instead of wrapping. */
    if (command == ROCKET_CMD_PING) {
      pendingPing = {};
      pendingPing.commandSequence = sequence;
      pendingPing.sentMs = nowMs;
      pendingPing.active = true;

      Serial.print("P,G,");
      Serial.print(sequence); Serial.print(',');
      Serial.print(nowMs); Serial.print(',');
      Serial.print(groundLastRssi, 1); Serial.print(',');
      Serial.print(groundLastSnr, 2); Serial.print(',');
      Serial.print(nowMs); Serial.print(',');
      Serial.print(groundTxSincePing); Serial.print(',');
      Serial.print(groundRxSincePing); Serial.print(',');
      Serial.print(groundTxErrorsSincePing); Serial.print(',');
      Serial.print(groundRxErrorsSincePing); Serial.print(',');
      Serial.print(groundLastRssi, 1); Serial.print(',');
      Serial.print(groundLastSnr, 2); Serial.println(",0");

      groundTxSincePing = 0;
      groundRxSincePing = 0;
      groundTxErrorsSincePing = 0;
      groundRxErrorsSincePing = 0;
    }

    rxFlag = false;
    const int state = radio.transmit(packet, ROCKET_PROTOCOL_HEADER_SIZE + 2u + payloadLength);
    rxFlag = false;  // TX-done can assert DIO1 while the receive callback is installed.

    if (state == RADIOLIB_ERR_NONE) {
      ++groundTxPackets;
      if (groundTxSincePing < 0xFFu) ++groundTxSincePing;
    } else {
      ++groundTxErrors;
      if (groundTxErrorsSincePing < 0xFFu) ++groundTxErrorsSincePing;
      if (command == ROCKET_CMD_PING) pendingPing.active = false;
      printGroundStatus(GS_STATUS_TRANSMIT_FAILED, state);
    }

    startReceiveMode();
    return state == RADIOLIB_ERR_NONE;
  }

badLength:
  printGroundStatus(GS_STATUS_SERIAL_BAD_FORMAT, command);
  return false;
badValue:
  printGroundStatus(GS_STATUS_SERIAL_BAD_VALUE, command);
  return false;
}

/* Non-blocking serial line collector. Call this every loop iteration so UART
 * commands are handled even while no radio packet is arriving. */
static void readSerialCommands() {
  static char line[96];
  static size_t used = 0;

  while (Serial.available() > 0) {
    const char c = static_cast<char>(Serial.read());
    if (c == '\r') continue;

    if (c == '\n') {
      if (used > 0) {
        line[used] = '\0';
        sendSerialCommand(line);
        used = 0;
      }
      continue;
    }

    if (used + 1u >= sizeof(line)) {
      used = 0;
      printGroundStatus(GS_STATUS_SERIAL_OVERFLOW, sizeof(line));
      continue;
    }

    line[used++] = c;
  }
}
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
void loop()
{
    /*
     * Continue checking USB/UART commands every loop iteration.
     */
    readSerialCommands();

    /*
     * No SX1280 receive interrupt has occurred.
     */
    if (!rxFlag)
    {
        return;
    }

    /*
     * Consume the current interrupt indication.
     *
     * After receive mode is restarted below, a new packet can set rxFlag
     * again while the current packet is being parsed and printed.
     */
    rxFlag = false;

    const size_t length = radio.getPacketLength();

    if (length > ROCKET_PROTOCOL_MAX_PACKET)
    {
        /*
         * Restart reception before printing the error. Serial output can take
         * long enough for the next multipart ACK to begin arriving.
         */
        startReceiveMode();

        printGroundStatus(
            GS_STATUS_PACKET_TOO_LARGE,
            static_cast<int32_t>(length));

        return;
    }

    uint8_t packet[ROCKET_PROTOCOL_MAX_PACKET];

    const int state = radio.readData(packet, length);

    if (state == RADIOLIB_ERR_NONE)
    {
        ++groundRxPackets;

        if (groundRxSincePing < 0xFFu)
        {
            ++groundRxSincePing;
        }

        /*
         * RSSI and SNR belong to the packet that was just read. Save them
         * before startReceiveMode() changes the radio state.
         */
        const float packetRssi = radio.getRSSI();
        const float packetSnr = radio.getSNR();

        groundLastRssi = packetRssi;
        groundLastSnr = packetSnr;

        /*
         * CRITICAL CHANGE:
         *
         * Rearm the SX1280 before parsing or printing the packet. PING and
         * diagnostics produce several ACK packets in rapid succession.
         */
        startReceiveMode();

        /*
         * Parsing can now safely perform Serial.print() operations while the
         * SX1280 is already listening for the next ACK.
         */
        parsePacket(
            packet,
            length,
            packetRssi,
            packetSnr);
    }
    else
    {
        ++groundRxErrors;

        if (groundRxErrorsSincePing < 0xFFu)
        {
            ++groundRxErrorsSincePing;
        }

        /*
         * Rearm reception before printing the error for the same reason:
         * UART output must not unnecessarily delay the next receive window.
         */
        startReceiveMode();

        printGroundStatus(
            GS_STATUS_RECEIVE_FAILED,
            state);
    }
}

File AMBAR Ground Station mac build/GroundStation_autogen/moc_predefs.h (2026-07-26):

#define ARCHITECTURE_ID "arm64"
#define QT_CHARTS_LIB 1
#define QT_CORE_LIB 1
#define QT_GUI_LIB 1
#define QT_NO_DEBUG 1
#define QT_OPENGLWIDGETS_LIB 1
#define QT_OPENGL_LIB 1
#define QT_SERIALPORT_LIB 1
#define QT_WIDGETS_LIB 1
#define SIZEOF_DPTR (sizeof(void*))
#define _LP64 1
#define __AARCH64EL__ 1
#define __AARCH64_CMODEL_SMALL__ 1
#define __AARCH64_SIMD__ 1
#define __APPLE_CC__ 6000
#define __APPLE__ 1
#define __ARM64_ARCH_8__ 1
#define __ARM_64BIT_STATE 1
#define __ARM_ACLE 200
#define __ARM_ALIGN_MAX_STACK_PWR 4
#define __ARM_ARCH 8
#define __ARM_ARCH_8_3__ 1
#define __ARM_ARCH_8_4__ 1
#define __ARM_ARCH_8_5__ 1
#define __ARM_ARCH_ISA_A64 1
#define __ARM_ARCH_PROFILE 'A'
#define __ARM_FEATURE_AES 1
#define __ARM_FEATURE_ATOMICS 1
#define __ARM_FEATURE_CLZ 1
#define __ARM_FEATURE_COMPLEX 1
#define __ARM_FEATURE_CRC32 1
#define __ARM_FEATURE_CRYPTO 1
#define __ARM_FEATURE_DIRECTED_ROUNDING 1
#define __ARM_FEATURE_DIV 1
#define __ARM_FEATURE_DOTPROD 1
#define __ARM_FEATURE_FMA 1
#define __ARM_FEATURE_FP16_FML 1
#define __ARM_FEATURE_FP16_SCALAR_ARITHMETIC 1
#define __ARM_FEATURE_FP16_VECTOR_ARITHMETIC 1
#define __ARM_FEATURE_FRINT 1
#define __ARM_FEATURE_IDIV 1
#define __ARM_FEATURE_JCVT 1
#define __ARM_FEATURE_LDREX 0xF
#define __ARM_FEATURE_NUMERIC_MAXMIN 1
#define __ARM_FEATURE_QRDMX 1
#define __ARM_FEATURE_RCPC 1
#define __ARM_FEATURE_SHA2 1
#define __ARM_FEATURE_SHA3 1
#define __ARM_FEATURE_SHA512 1
#define __ARM_FEATURE_SM3 1
#define __ARM_FEATURE_SM4 1
#define __ARM_FEATURE_UNALIGNED 1
#define __ARM_FP 0xE
#define __ARM_FP16_ARGS 1
#define __ARM_FP16_FORMAT_IEEE 1
#define __ARM_NEON 1
#define __ARM_NEON_FP 0xE
#define __ARM_NEON__ 1
#define __ARM_PCS_AAPCS64 1
#define __ARM_SIZEOF_MINIMAL_ENUM 4
#define __ARM_SIZEOF_WCHAR_T 4
#define __ATOMIC_ACQUIRE 2
#define __ATOMIC_ACQ_REL 4
#define __ATOMIC_CONSUME 1
#define __ATOMIC_RELAXED 0
#define __ATOMIC_RELEASE 3
#define __ATOMIC_SEQ_CST 5
#define __BIGGEST_ALIGNMENT__ 8
#define __BITINT_MAXWIDTH__ 128
#define __BLOCKS__ 1
#define __BOOL_WIDTH__ 8
#define __BYTE_ORDER__ __ORDER_LITTLE_ENDIAN__
#define __CHAR16_TYPE__ unsigned short
#define __CHAR32_TYPE__ unsigned int
#define __CHAR_BIT__ 8
#define __CLANG_ATOMIC_BOOL_LOCK_FREE 2
#define __CLANG_ATOMIC_CHAR16_T_LOCK_FREE 2
#define __CLANG_ATOMIC_CHAR32_T_LOCK_FREE 2
#define __CLANG_ATOMIC_CHAR_LOCK_FREE 2
#define __CLANG_ATOMIC_INT_LOCK_FREE 2
#define __CLANG_ATOMIC_LLONG_LOCK_FREE 2
#define __CLANG_ATOMIC_LONG_LOCK_FREE 2
#define __CLANG_ATOMIC_POINTER_LOCK_FREE 2
#define __CLANG_ATOMIC_SHORT_LOCK_FREE 2
#define __CLANG_ATOMIC_WCHAR_T_LOCK_FREE 2
#define __CONSTANT_CFSTRINGS__ 1
#define __DBL_DECIMAL_DIG__ 17
#define __DBL_DENORM_MIN__ 4.9406564584124654e-324
#define __DBL_DIG__ 15
#define __DBL_EPSILON__ 2.2204460492503131e-16
#define __DBL_HAS_DENORM__ 1
#define __DBL_HAS_INFINITY__ 1
#define __DBL_HAS_QUIET_NAN__ 1
#define __DBL_MANT_DIG__ 53
#define __DBL_MAX_10_EXP__ 308
#define __DBL_MAX_EXP__ 1024
#define __DBL_MAX__ 1.7976931348623157e+308
#define __DBL_MIN_10_EXP__ (-307)
#define __DBL_MIN_EXP__ (-1021)
#define __DBL_MIN__ 2.2250738585072014e-308
#define __DECIMAL_DIG__ __LDBL_DECIMAL_DIG__
#define __DEPRECATED 1
#define __DYNAMIC__ 1
#define __ENVIRONMENT_MAC_OS_X_VERSION_MIN_REQUIRED__ 140000
#define __ENVIRONMENT_OS_VERSION_MIN_REQUIRED__ 140000
#define __EXCEPTIONS 1
#define __FINITE_MATH_ONLY__ 0
#define __FLT16_DECIMAL_DIG__ 5
#define __FLT16_DENORM_MIN__ 5.9604644775390625e-8F16
#define __FLT16_DIG__ 3
#define __FLT16_EPSILON__ 9.765625e-4F16
#define __FLT16_HAS_DENORM__ 1
#define __FLT16_HAS_INFINITY__ 1
#define __FLT16_HAS_QUIET_NAN__ 1
#define __FLT16_MANT_DIG__ 11
#define __FLT16_MAX_10_EXP__ 4
#define __FLT16_MAX_EXP__ 16
#define __FLT16_MAX__ 6.5504e+4F16
#define __FLT16_MIN_10_EXP__ (-4)
#define __FLT16_MIN_EXP__ (-13)
#define __FLT16_MIN__ 6.103515625e-5F16
#define __FLT_DECIMAL_DIG__ 9
#define __FLT_DENORM_MIN__ 1.40129846e-45F
#define __FLT_DIG__ 6
#define __FLT_EPSILON__ 1.19209290e-7F
#define __FLT_HAS_DENORM__ 1
#define __FLT_HAS_INFINITY__ 1
#define __FLT_HAS_QUIET_NAN__ 1
#define __FLT_MANT_DIG__ 24
#define __FLT_MAX_10_EXP__ 38
#define __FLT_MAX_EXP__ 128
#define __FLT_MAX__ 3.40282347e+38F
#define __FLT_MIN_10_EXP__ (-37)
#define __FLT_MIN_EXP__ (-125)
#define __FLT_MIN__ 1.17549435e-38F
#define __FLT_RADIX__ 2
#define __FP_FAST_FMA 1
#define __FP_FAST_FMAF 1
#define __GCC_ATOMIC_BOOL_LOCK_FREE 2
#define __GCC_ATOMIC_CHAR16_T_LOCK_FREE 2
#define __GCC_ATOMIC_CHAR32_T_LOCK_FREE 2
#define __GCC_ATOMIC_CHAR_LOCK_FREE 2
#define __GCC_ATOMIC_INT_LOCK_FREE 2
#define __GCC_ATOMIC_LLONG_LOCK_FREE 2
#define __GCC_ATOMIC_LONG_LOCK_FREE 2
#define __GCC_ATOMIC_POINTER_LOCK_FREE 2
#define __GCC_ATOMIC_SHORT_LOCK_FREE 2
#define __GCC_ATOMIC_TEST_AND_SET_TRUEVAL 1
#define __GCC_ATOMIC_WCHAR_T_LOCK_FREE 2
#define __GCC_HAVE_DWARF2_CFI_ASM 1
#define __GCC_HAVE_SYNC_COMPARE_AND_SWAP_1 1
#define __GCC_HAVE_SYNC_COMPARE_AND_SWAP_2 1
#define __GCC_HAVE_SYNC_COMPARE_AND_SWAP_4 1
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
